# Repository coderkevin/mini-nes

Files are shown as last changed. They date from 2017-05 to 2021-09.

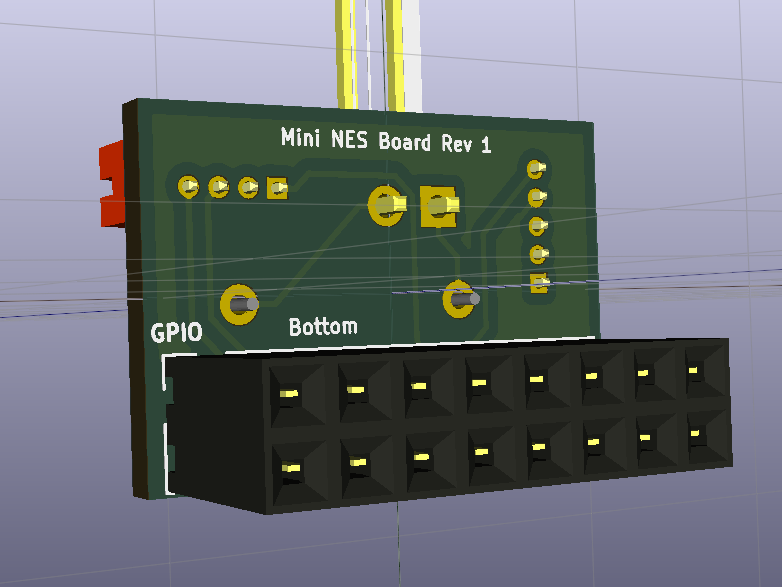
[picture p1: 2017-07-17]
pcb-board/main-board/main-board-back.png

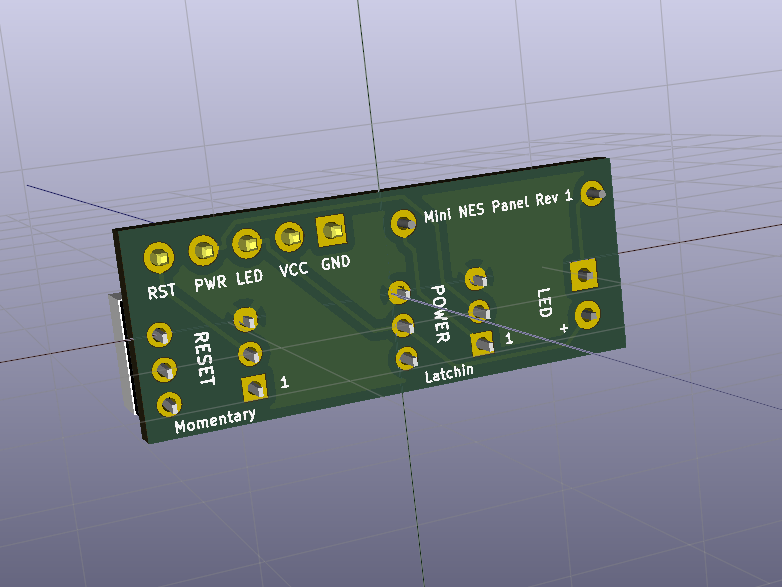
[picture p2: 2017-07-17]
pcb-board/front-panel/front-panel-back.png

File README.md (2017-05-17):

# mini-nes
Support code for my version of a RPi-based Mini NES

This is based on/inspired by [DaftMike's NESPi](http://www.daftmike.com/2016/07/NESPi.html)
It is compatible with the 3D printed parts, but the hardware set up is simplified:

- No Arduino board needed, only the Raspberry Pi
- No power board support (In CPU shutdown, the RPi uses less power than the USB power supply you're using to power it)
- No fan support (buy good heatsinks, you likely won't miss the fan)

Here's a more detailed list of the features:

## Latching Power Button

The Power button is handled via GPIO and reset pin on the RPi.
The power button, when latched, brings the reset pin high, awakening the RPi from its shutdown.
After the RPi is powered up, a script is used on an output GPIO pin to hold the reset pin high in addition to the power button.
When the power button is unlatched, the GPIO holds the reset pin high until system shutdown completes.

## Power LED

The Power LED is connected to the reset pin, this indicates the true run state of the RPi. If the reset pin is high, the RPi is running. If the reset pin is low, then the RPi is held in reset and the CPU is in shutdown. It looks a little strange to see the power LED remain lit for a few seconds after unlatching the power button, but it is reassuring to know that the RPi isn't being subjected to a hard reset.

## Reset Button

The Reset button is connected to an RPi GPIO and simply does a system reboot.

## NFC Cartidge support

The NFC Reader is a PN532 running on the RPi's i2c interface. I've made a simple c interface to Python to utilize it. No Arduino or microcontroller needed to use it.

## No NFC tag writing needed

This system is designed to simply rely on the unique IDs already imprinted on your NFC tags. It uses a configuration file to map those UIDs to the correct game files to be run.

## Immediate loading of games

The system doesn't have to be powered off to start a game. It continually scans for cartridges and will restart Emulation Station as soon as a cart is installed. Don't worry if you like the feel of the old process though. You can still power off the system and install your cart and power it back on if you like.

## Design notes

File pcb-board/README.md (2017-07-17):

# KiCad PCB projects
This are the Front and Main PCB projects designed on KiCad, this PCB is designed to be as easy to solder as possible using all through hole components. The NFC and
Front Panel connector are 1.25mm pitch and require careful soldering to avoid bridging solder points.

## BOM

This is the list of components and there respectable links to order each part from different suppliers:

Front Panel
- 150ohm Power LED Resistor, Quantity: 1 digikey: http://bit.ly/2qCImqK
- Front Panel Power LED, Quantity: 1 digikey: http://bit.ly/2qCURmf
- Latching Push Button Switche (Power Switch) Quantity: 1 amazon: http://amzn.to/2rpfMua
- Momentary Push Button Switch (Reset Switch) Quantity: 1 amazon: http://amzn.to/2rpqrF1

Main Board
- Micro JST Picoblade 1.25mm Pitch 4 Pin(NFC Reader) Quantity: 1 ebay: http://ebay.to/2sDfNLq
- Micro JST Picoblade 1.25mm Pitch 5 Pin(Front Control Panel) Quantity: 1 ebay: http://ebay.to/2sDwypP
- Resistor 10kohm, Quantity: 1 digikey: http://bit.ly/2rpp1KH
- 16 Pin Pi Header Connector, Quantity: 1 digikey: http://bit.ly/2rp8Ehp

## OSH Park Links
This PCB projects are publicly shared at oskpark.com you can order this boards from the following links:

-Front Panel PCB
https://oshpark.com/shared_projects/b4CEMlJS

-Main Board PCB
https://oshpark.com/shared_projects/rdgBPoq0

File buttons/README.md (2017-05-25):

# Mini NES Power Buttons

This software is designed to work with two buttons:

1. A latching DPDT "Power" switch.
2. A momentary "Reset" switch.

## Reset Switch

This one is easy, it's simply connected to a GPIO and when pressed, the `nes_buttons` daemon issues the `shutdown -r now` command to reboot the system.

## Power Switch

This one is a little trickier. The goal of powering down the system in this way is to ensure as low power usage as possible. For this to happen, the main CPU has to be shut down. That's done easily enough via a `shutdown -h now` command, but in order for the RPi to start back up from that state, the "RUN" pin has to be toggled.

The key part of this system is the RUN pin. This is pin 1 of the RUN header. It sits at 3.3v normally, but if it's pulled down low, it does a hard reset of the RPi. And then it must rise back up to 3.3v for the RPi to start back up.

The theory behind this system is:

 1. A pull-down resistor (10k) is used to pull the RUN pin down by default. This holds the RPi in reset until you push the power button.
 2. When you push the latching power button, it supplies 3.3v to the RUN pin. This brings the RPi out of reset and it boots up.
 3. Upon startup, the `nes_buttons` daemon sets a GPIO to also supply 3.3v to the RUN pin. This ensures the RPi doesn't do a hard reset when you release the latching power button.
 4. When you push the latching power button, it no longer supplies 3.3v to the RUN pin, but the RPi doesn't go into reset because the GPIO is still holding it up to 3.3v. However, the other pins on the power button let the `nes_buttons` daemon know that the power button was released. This runs the `shutdown -h now` command.
 5. The RPi then begins the shutdown process as normal, doing critical things like ensuring all the writes to the SD card are completed (this is why it's bad to pull power on a Pi).
 6. At some point in the shutdown process, the GPIO system is shut down. When this happens, the GPIO that was holding up the RUN pin to 3.3v falls.
 7. Given that there is nothing supplying voltage to the RUN pin, the pull-down resistor takes over and pulls the RUN pin to ground. (on my RPi 3 with a 10k resistor, it is about 0.5v)

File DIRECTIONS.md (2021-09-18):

# Mini NES Setup

## Prerequisites

1. Ensure Python 2.7 is working correctly and installed in `/usr/bin/python2.7`
2. `sudo apt-get install python-dev python-pip`
3. `sudo pip install python-daemon==2.2.4` (this is necessary to fix an issue with the latest release of python-daemon)

## Enable i2c device
1. `sudo mkdir /etc/nfc`
2. `sudo raspi-config`
3. Select "5 Interfacing"
4. Select "P5 I2C"
5. Select "\<Yes\>"
6. Exit `raspi-config` program
7. `sudo shutdown -r now` to reboot with i2c enabled.

## Install libnfc
1. Ensure you are logged in as `pi` and in the `/home/pi` directory.
2. `wget -O libnfc-1.7.1.tar.bz2 https://bintray.com/nfc-tools/sources/download_file?file_path=libnfc-1.7.1.tar.bz2`
3. `tar -xvf libnfc-1.7.1.tar.bz2`
4. `cd libnfc-1.7.1`
5. `./configure --prefix=/usr --sysconfdir=/etc --with-drivers=pn532_i2c`
6. `make`
7. `sudo make install`
8. After reboot, type `lsmod |grep i2c` and ensure that you see an `i2c_dev` in the list.
9. Also, type `ls /dev/i2c*` and ensure that `/dev/i2c-1` is returned.

## Configure libnfc
1. `sudo nano /etc/nfc/libnfc.conf`
2. Cut and paste the following and save the file.
```
# Allow device auto-detection (default: true)
# Note: if this auto-detection is disabled, user has to manually set a device
# configuration using file or environment variable
allow_autoscan = true

# Allow intrusive auto-detection (default: false)
# Warning: intrusive auto-detection can seriously disturb other devices
# This option is not recommended, so user should prefer to add manually his/her device.
allow_intrusive_scan = false

# Set log level (default: error)
# Valid log levels are (in order of verbosity): 0 (none), 1 (error), 2 (info), 3 (debug)
# Note: if you compiled with --enable-debug option, the default log level is "debug"
log_level = 1

# Manually set default device (no default)
# To set a default device, users must set both name and connstring for their device
# Note: if autoscan is enabled, default device will be the first device available in device list.
device.name = "PN532"
device.connstring = "pn532_i2c:/dev/i2c-1"
```
3. Run `nfc-poll` and ensure you see `NFC reader: pn532_i2c:/dev/i2c-1 opened`
4. Try reading a tag, use Ctrl-C to stop or just wait 30 seconds

## Install nfc_poll
1. Ensure you are logged in as `pi` and in the `/home/pi` directory.
2. `export NFC_HOME=/home/pi/libnfc-1.7.1`
3. `git clone https://github.com/coderkevin/mini-nes.git`
4. `cd mini-nes/nfc`
5. `make`
6. `sudo make install`
7. Run `systemctl status nfc_poll` and ensure you see "Active: active (running)" in the output

## Configure your cartridges

In this system, the cartridges don't need to be written to, we configure a mapping to their UIDs, which should already be uniquely pre-programmed to each tag.

### Record your NFC tag UIDs
1. Run `tail -f /dev/shm/nfc_poll.log`
2. Place a cartridge (NFC tag) over the reader, the log should output "Reading NFC UID: 00000000000000" where the zeroes are the UID of the tag.
3. Copy/paste the UID into a text file.
4. Continue with all tags you wish to use.
5. To exit the log, hit \<Ctrl\>-C

### Record your desired games
1. `cd ~/RetroPie/roms`
2. Start typing `ls <system>/<name of game>` (e.g. `ls nes/Super`) to find the rom you want. Hit tab to complete the file, or hit tab twice to show possible matches. Don't forget to backslash things like spaces and parenthesis as you go.
3. After you finally tab through to the complete file, hit <enter>.
4. Copy the resulting line and put it and put it next to the UID you want to use in your text file. (`e.g. nes/Super Mario Bros. (JU) [!].zip`) Make sure you don't have backslashes here.
5. Repeat this process

### Write your cartridges in the config
1. `sudo nano /etc/nfc_poll/nfc_poll.conf`
2. At the bottom of the file, there's a `[Cartridges]` section.
3. For each cartridge you want, add a line in this format: `<uid> = <game file>` (e.g. `00000000000000 = nes/Super Mario Bros. (JU) [!].zip`)
4. `sudo systemctl restart nfc_poll`
5. Try it out! Place one of your cartridges on the reader and the screen should go black for a couple seconds, then bring up your game. Remove it and it should go back to the dashboard.

## Install nes_buttons
1. Ensure you are logged in as `pi` and in the `/home/pi` directory.
2. (If you haven't already) `git clone https://github.com/coderkevin/mini-nes.git`
3. `cd mini-nes/buttons`
4. `sudo make install`
5. Run `systemctl status nes_buttons` and ensure you see "Active: active (running)" in the output
6. From here, you should be able to depress the power button to release it, and the LED should stay lit until the shutdown completes, then turn off. At this point, your RPi CPU is completely off. Now press the power button to latch it, and the RPi should come back up. A reset will simply send a `shutdown -r now` instead and reboot the system.

## Install screen_manager
1. Ensure you are logged in as `pi` and in the `/home/pi` directory.
2. (If you haven't already) `git clone https://github.com/coderkevin/mini-nes.git`
3. `cd mini-nes/screen`
4. `sudo make install`
5. Restart your Pi (try the reset button!) and if you've done all the steps above, everything should be working!

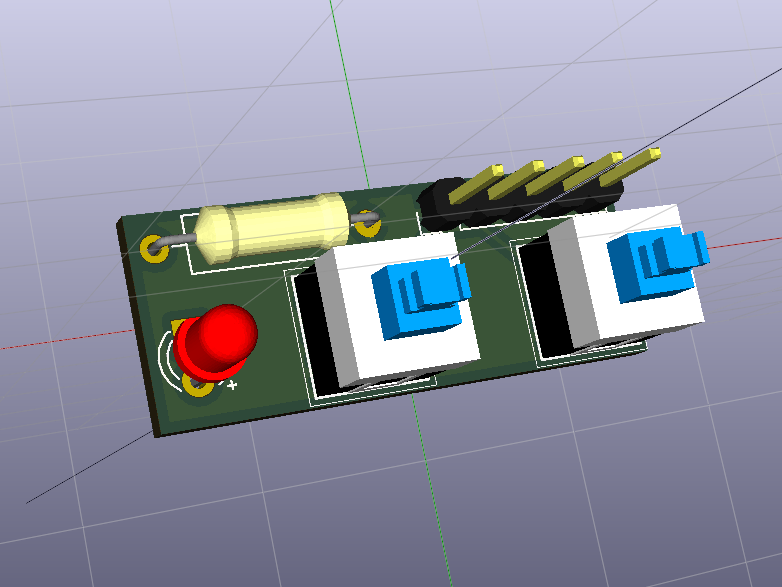
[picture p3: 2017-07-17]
pcb-board/front-panel/front-panel-front.png

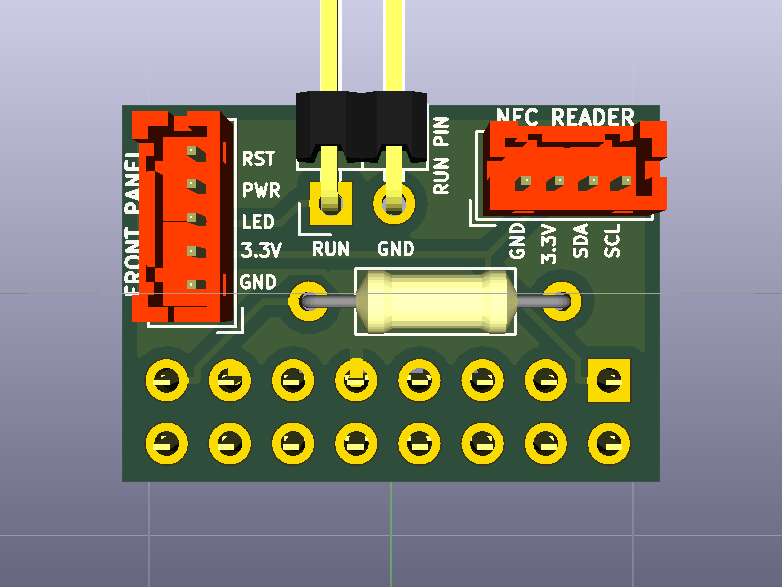
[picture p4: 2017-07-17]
pcb-board/main-board/main-board-front.png

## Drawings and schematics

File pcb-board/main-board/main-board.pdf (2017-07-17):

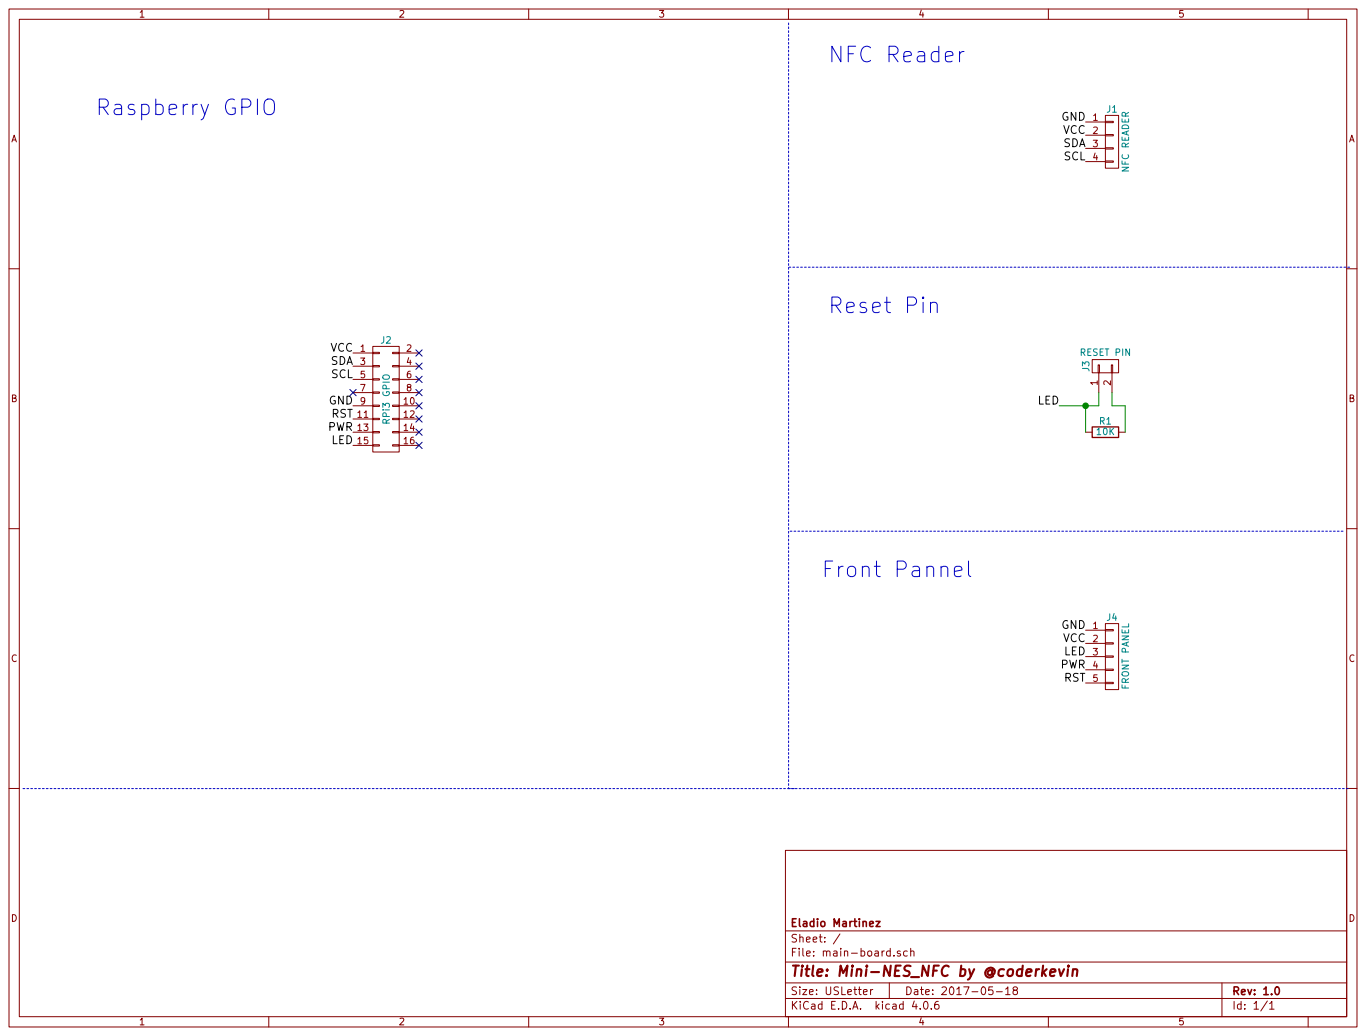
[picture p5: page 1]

File: main-board.sch Sheet: / Eladio Martinez

Id: 1/1 Title: Mini-NES_NFC by @coderkevin

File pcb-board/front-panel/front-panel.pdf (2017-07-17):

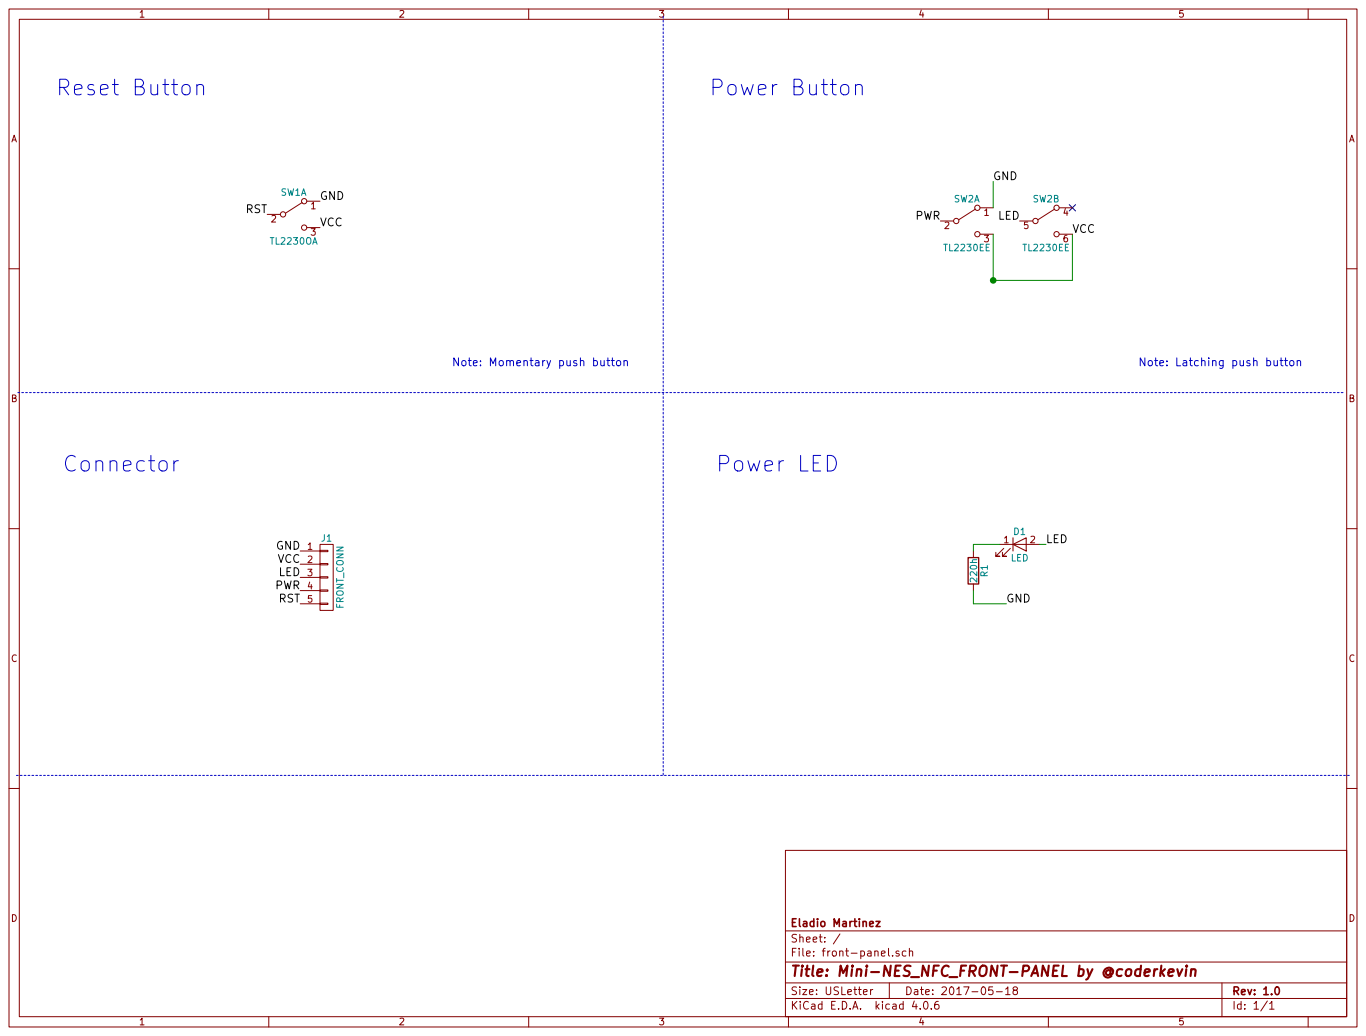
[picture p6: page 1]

File: front-panel.sch Sheet: / Eladio Martinez

Id: 1/1 Title: Mini-NES_NFC_FRONT-PANEL by @coderkevin

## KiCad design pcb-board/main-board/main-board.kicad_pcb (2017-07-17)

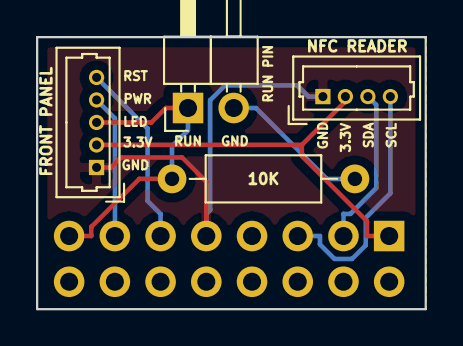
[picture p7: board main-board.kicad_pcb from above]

Board: 2 copper layers, 21.6 x 15.1 mm, 5 parts (1 on the bottom side), 8 nets.

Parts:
10K: 10K; R_Axial_DIN0207_L6.3mm_D2.5mm_P10.16mm_Horizontal
FRONT PANEL: FRONT PANEL; Molex_PicoBlade_53047-0510_05x1.25mm_Straight
GPIO: RPi3 GPIO; Socket_Strip_Straight_2x08_Pitch2.54mm
NFC READER: NFC READER; Molex_PicoBlade_53047-0410_04x1.25mm_Straight
RUN PIN: RESET PIN; Pin_Header_Angled_1x02_Pitch2.54mm

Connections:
/GND: FRONT PANEL.1, GPIO.9, NFC READER.1
/LED: 10K.1, FRONT PANEL.3, GPIO.15, RUN PIN.1
/PWR: FRONT PANEL.4, GPIO.13
/RST: FRONT PANEL.5, GPIO.11
/SCL: GPIO.5, NFC READER.4
/SDA: GPIO.3, NFC READER.3
/VCC: FRONT PANEL.2, GPIO.1, NFC READER.2
unnamed: 10K.2, RUN PIN.2

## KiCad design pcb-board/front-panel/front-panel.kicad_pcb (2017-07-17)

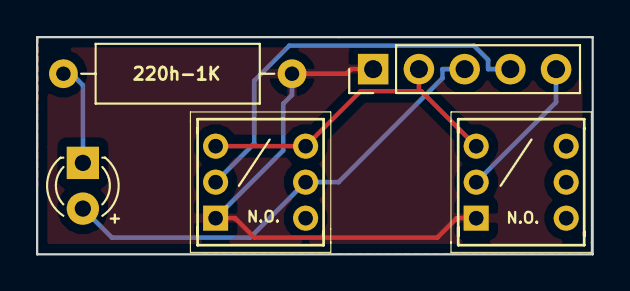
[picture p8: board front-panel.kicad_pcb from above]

Board: 2 copper layers, 30.9 x 12.1 mm, 5 parts (0 on the bottom side), 6 nets.

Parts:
220h-1K: 220h; R_Axial_DIN0309_L9.0mm_D3.2mm_P12.70mm_Horizontal
J1: FRONT_CONN; Pin_Header_Straight_1x05_Pitch2.54mm
LED: LED; LED_D3.0mm
POWER: TL2230EE; TL2230
RESET: TL2230OA; TL2230

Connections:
/GND: 220h-1K.2, J1.1, POWER.1, RESET.1
/LED: J1.3, LED.2, POWER.5
/PWR: J1.4, POWER.2
/RST: J1.5, RESET.2
/VCC: J1.2, POWER.3, POWER.6, RESET.3
unnamed: 220h-1K.1, LED.1

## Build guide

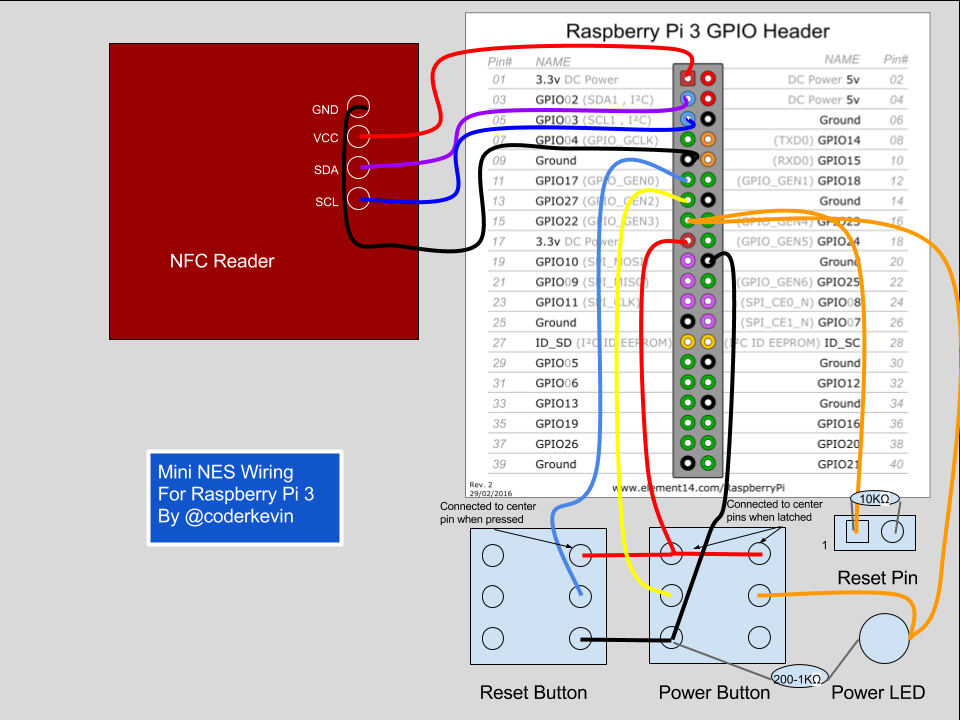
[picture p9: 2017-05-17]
Mini NES Wiring.png

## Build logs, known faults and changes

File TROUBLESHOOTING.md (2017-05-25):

# Mini NES Troubleshooting Guide

Things not working the way they should? Check here for some tactics on diagnosing your problem.

## Power Buttons

### Software

- Program: `nes_buttons` daemon (should be running on system startup)
- How to start: `sudo systemctl start nes_buttons`
- How to stop: `sudo systemctl stop nes_buttons`
- How to check the log: `cat /dev/shm/nes_buttons.log`

If the system daemon isn't behaving the way you'd expect, you can run the code manually.

1. `sudo systemctl stop nes_buttons`
2. Change your directory to the `buttons` subdirectory of the source.
3. `python nes_buttons.py`
4. Logging output should be visible on the command line. (If you see a "RuntimeWarning" about a channel already in use, that's okay.)
5. Press the reset button. You should see logging output about restarting.

### Electrical

If your power isn't shuttting down and starting back up correctly, here are a couple things to check:

1. Ensure the power button is unlatched and then plug in the RPi power.
2. Use a multimeter to test for voltage on RUN pin #1. It should be around 0.5v or less.
3. Press the power button to latch it.
4. The LED should turn on, indicating that RUN pin #1 has risen in voltage.
5. The system should power up as normal.

If your RPi turns off but not back on, it's likely because the RUN pin isn't pulled low enough before rising back to 3.3v. On my RPi 3, a 10k is enough to drop the RUN pin to 0.5v. Check with a multimeter when the device is plugged in, but the power button is not on. If it's too high, then try a lower value resistor. Something between 10k down to 1k should work. When you try out a different resistor, test the voltage, then try the behavior.

## NFC Reader

### Software

- Program: `nfc_poll` daemon (should be running on system startup)
- How to start: `sudo systemctl start nfc_poll`
- How to stop: `sudo systemctl stop nfc_poll`
- How to check the log: `cat /dev/shm/nfc_poll.log`

If the system daemon isn't behaving the way you'd expect, you can run the code manually.

1. `sudo systemctl stop nfc_poll`
2. Change your directory to the `nfc` subdirectory of the source.
3. `python nfc_poll.py`
4. Logging output should be visible on the command line.
5. Try placing a cartridge over the sensor and watch for output.

### Electrical

If your nfc reader isn't working correctly, it should show up in the logs. If you suspect it's electrical, here are some things to check:

1. There are two small DIP switches on the NFC board to select the mode. Ensure they're set correctly for i2c.
2. Ensure the correct pins are connected to the RPi header and the NFC board. Revisit the wiring diagram for this.
3. The red LED on the NFC board should be on any time the RPi header is plugged in.

## Screen Manager

### Software

- Script: `/var/lib/screen_manager/screen_manager.py` (called by autostart.sh)
- How to check the log: `cat /dev/shm/screen_manager.log`

This script should be fairly stable and shouldn't have too many problems. If emulationstation is running on startup, then this script is running.

The installation for this script modifies `/opt/retropie/configs/all/autostart.sh`. It comments out emulationstation and adds `python screen_manager.py` instead. If this is causing problems, you can edit this file and restore default operation there.

You can run this script manually just like the others, but you'll want to disable it in `autostart.sh` before you do.

To test:

1. Edit the config file at `cat /dev/shm/screen_manager.cfg` in accordance with [the screen readme](https://github.com/coderkevin/mini-nes/blob/master/screen/README.md)
2. Try a `dashboard` action.
3. Try a `rom` action.
4. Try deleting the file to ensure the default dashboard action runs.

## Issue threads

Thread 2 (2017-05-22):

Joystick/Game Pad doesn't work upon cart load

coderkevin, 2017-05-22:
When a cartridge is placed of the NFC sensor and the corresponding game is loaded, the game pad doesn't work.

coderkevin, 2017-05-24:
This has been fixed with the addition of the `screen_manager`

Closed 2017-05-24.

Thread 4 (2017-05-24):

screen_manager: Clear console screen before running action

coderkevin, 2017-05-24:
Right now, the default RetroPie console login screen is visible after the action starts but before it takes over the framebuffer. The simplest thing to do to fix this is to ensure the console is cleared before starting the action process.

coderkevin, 2017-05-24:
This doesn't seem to be happening anymore. Closing.

Closed 2017-05-24.

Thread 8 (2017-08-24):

NFC error

number12, 2017-08-24:
I followed all the instructions and python is installed correctly. The button code does work and the process is running. Anyways I skipped the NFC a couple times because of this error and got a new NFC reader incase, and still same error. Wondering if there is a fix Everything goes smoothly but when I type the command "nfc-poll" it gives the following error

> pi@retropie:~ $ nfc-poll
nfc-poll uses libnfc 1.7.1
error   libnfc.bus.i2c  Error: wrote only -1 bytes (10 expected).
error   libnfc.driver.pn532_i2c Unable to transmit data. (TX)
pn53x_check_communication: Input / Output Error
error   libnfc.bus.i2c  Error: wrote only -1 bytes (10 expected).
error   libnfc.driver.pn532_i2c Unable to transmit data. (TX)
nfc-poll: ERROR: Unable to open NFC device.

Wondering if I did something wrong? I wired it correctly im sure. Thanks for help.
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

Xerxes3rd, 2017-10-10:
@number12 It looks like you might have the DIP switches on the NFC board set to SPI instead of I2C.

thepiwizard, 2021-09-17:
very last step fails
also the tail nfc-poll thing fails

pi@retropie:~ $ sudo systemctl restart nfc_poll

Job for nfc_poll.service failed because the control process exited with error code.
See "systemctl status nfc_poll.service" and "journalctl -xe" for details.
pi@retropie:~ $ systemctl status nfc_poll.service
â— nfc_poll.service - LSB: start and stop nfc_poll server
   Loaded: loaded (/etc/init.d/nfc_poll; generated)
   Active: failed (Result: exit-code) since Fri 2021-09-17 19:33:41 BST; 11s ago
     Docs: man:systemd-sysv-generator(8)
  Process: 2371 ExecStart=/etc/init.d/nfc_poll start (code=exited, status=1/FAILURE)

Sep 17 19:33:41 retropie nfc_poll[2371]: Traceback (most recent call last):
Sep 17 19:33:41 retropie nfc_poll[2371]:   File "/var/lib/nfc_poll/nfc_poll_daemon.py", line 64, in <module>
Sep 17 19:33:41 retropie nfc_poll[2371]:     start_daemon( args.pid_file, args.log_file )
Sep 17 19:33:41 retropie nfc_poll[2371]:   File "/var/lib/nfc_poll/nfc_poll_daemon.py", line 54, in start_daemon
Sep 17 19:33:41 retropie nfc_poll[2371]:     sys.exit(1)
Sep 17 19:33:41 retropie nfc_poll[2371]: NameError: global name 'sys' is not defined
Sep 17 19:33:41 retropie nfc_poll[2371]:  failed!
Sep 17 19:33:41 retropie systemd[1]: nfc_poll.service: Control process exited, code=exited, status=1/FAILURE
Sep 17 19:33:41 retropie systemd[1]: nfc_poll.service: Failed with result 'exit-code'.
Sep 17 19:33:41 retropie systemd[1]: Failed to start LSB: start and stop nfc_poll server.
pi@retropie:~ $

coderkevin, 2021-09-18:
Fixed in 3b26b25633fca2e90fd475dfe22be0519cc7030a

Closed 2021-09-18.

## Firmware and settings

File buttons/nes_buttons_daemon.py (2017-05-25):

#!/usr/bin/env python2.7

import sys
import traceback
import argparse
import signal
import grp
import daemon
from daemon import pidfile
import log
import logging
import nes_buttons

debug_p = True

def start_daemon( pidf, logf ):
    # This launches the daemon in its context

    global debug_p

    if debug_p:
        print( "nes_buttons_daemon: entered start_daemon()" )
        print( "nes_buttons_daemon: pidf={} logf={}".format( pidf, logf ) )

    try:
        with daemon.DaemonContext(
            working_directory='/var/lib/nes_buttons',
            gid = grp.getgrnam( 'pi' ).gr_gid,
            umask=0o002,
            pidfile=pidfile.TimeoutPIDLockFile( pidf ),
            ) as context:

            logLevel = logging.INFO
            logFormat = '%(asctime)s - %(name)s - %(levelname)s - %(message)s'

            logger = log.initLogger( logLevel, logFormat, logf )
            logger.info( "nes_buttons_daemon: entered daemon context" )

            try:
                app = nes_buttons.NESButtons( logger )
                logger.info( "nes_buttons_daemon: running app" )
                app.run()
            except:
                logger.error( traceback.format_exc() )
                sys.exit(1)

    except:
        print( "Unhandled exception: {}".format( traceback.format_exc() ) )
        sys.exit(1)

if __name__ == "__main__":
    parser = argparse.ArgumentParser( description="NES Buttons Daemon" )
    parser.add_argument( '-p', '--pid-file', default='/var/run/nes_buttons.pid' )
    parser.add_argument( '-l', '--log-file', default='/dev/shm/nes_buttons.log' )

    args = parser.parse_args()

    start_daemon( args.pid_file, args.log_file )

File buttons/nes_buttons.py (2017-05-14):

#!/usr/bin/env python2.7

import sys
import time
import subprocess
import traceback
import log
import logging
import RPi.GPIO as GPIO

# Pin Mappings
RESET_SENSE_PIN = 11
POWER_SENSE_PIN = 13
POWER_HOLD_PIN = 15

class NESButtons():
    def __init__( self, logger ):
        self.logger = logger
        self.mode = 'init'

        self.logger.info( "Initializing NES button controls" )

        GPIO.setmode( GPIO.BOARD )
        GPIO.setup( RESET_SENSE_PIN, GPIO.IN, pull_up_down=GPIO.PUD_DOWN )
        GPIO.setup( POWER_SENSE_PIN, GPIO.IN, pull_up_down=GPIO.PUD_DOWN )
        GPIO.setup( POWER_HOLD_PIN, GPIO.OUT )

        # This is the only thing that keeps the RPi alive after the
        # power button is released. We never turn this pin low because
        # the system will hard-reset if we do. We wait for shutdown
        # to take down the GPIO system with it.
        GPIO.output( POWER_HOLD_PIN, GPIO.HIGH )

        self.addHandlers()

    def addHandlers( self ):
        GPIO.add_event_detect(
            RESET_SENSE_PIN,
            GPIO.RISING,
            callback=self.resetPressed,
            bouncetime=500
            )

        GPIO.add_event_detect(
            POWER_SENSE_PIN,
            GPIO.FALLING,
            callback=self.powerPressed,
            bouncetime=500
            )

    def removeHandlers( self ):
        GPIO.remove_event_detect( RESET_SENSE_PIN )
        GPIO.remove_event_detect( POWER_SENSE_PIN )

    def run( self ):
        self.mode = 'run'

        while True:
            time.sleep(5)
            if 'run' != self.mode:
                self.logger.info( "{}ing...".format( self.mode ) )

    def resetPressed( self, channel ):
        self.removeHandlers()
        self.mode = 'restart'
        self.logger.info( "Restarting system..." )
        subprocess.call( "sudo shutdown -r now", shell=True )

    def powerPressed( self, channel ):
        self.removeHandlers()
        self.mode = 'halt'
        self.logger.info( "Powering system down..." )
        subprocess.call( "sudo shutdown -h now", shell=True )

if __name__ == "__main__":
    logLevel = logging.DEBUG
    logFormat = '%(asctime)s - %(name)s - %(levelname)s - %(message)s'

    logger = log.initLogger( logLevel, logFormat )

    try:
        app = NESButtons( logger )
        app.run()
    except:
        logger.error( traceback.format_exc() )
        sys.exit(1)

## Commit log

2017-05-14 Add power sense to main loop
2017-05-17 Add wiring diagram
2017-05-24 nfc_poll: use screen_manager
    This switches nfc_poll to use the screen_manager config
    file to start games and the dashboard.
2017-05-24 Move logs to /dev/shm
    This moves logs for nfc_poll and nes_buttons to /dev/shm
    This is where the rest of the RetroPie logs are, and it's in memory so
    it prevents the logs from thrashing the SD card.
    [nes_buttons_daemon.py]
2017-05-25 nes_buttons: remove references to 'nes' user.
    I stopped using the nes user in this configuration, but there were a
    couple left-over places that referenced it.
2017-07-17 Add KiCad Front and Main PCB project files (#5)
    [front-panel.kicad_pcb, front-panel.sch, main-board.kicad_pcb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]
